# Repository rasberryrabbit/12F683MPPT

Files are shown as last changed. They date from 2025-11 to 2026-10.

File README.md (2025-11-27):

# 12F683MPPT
Simple MPPT with 12F683  
  
Another porting of MPPT. Test ok. Switching frequency : 10kHz.  
It has no switching noise.  
  
BUK9508-55A for alternative FET. 
  
TLC272 OPAMP works better. MCP602 is better for low temperature condition.  
  
(Note) Sometimes MPPT stalls no output. It caused by low FET bootstrap voltage.  
It's very rare condition. It may fixed by R9 change.

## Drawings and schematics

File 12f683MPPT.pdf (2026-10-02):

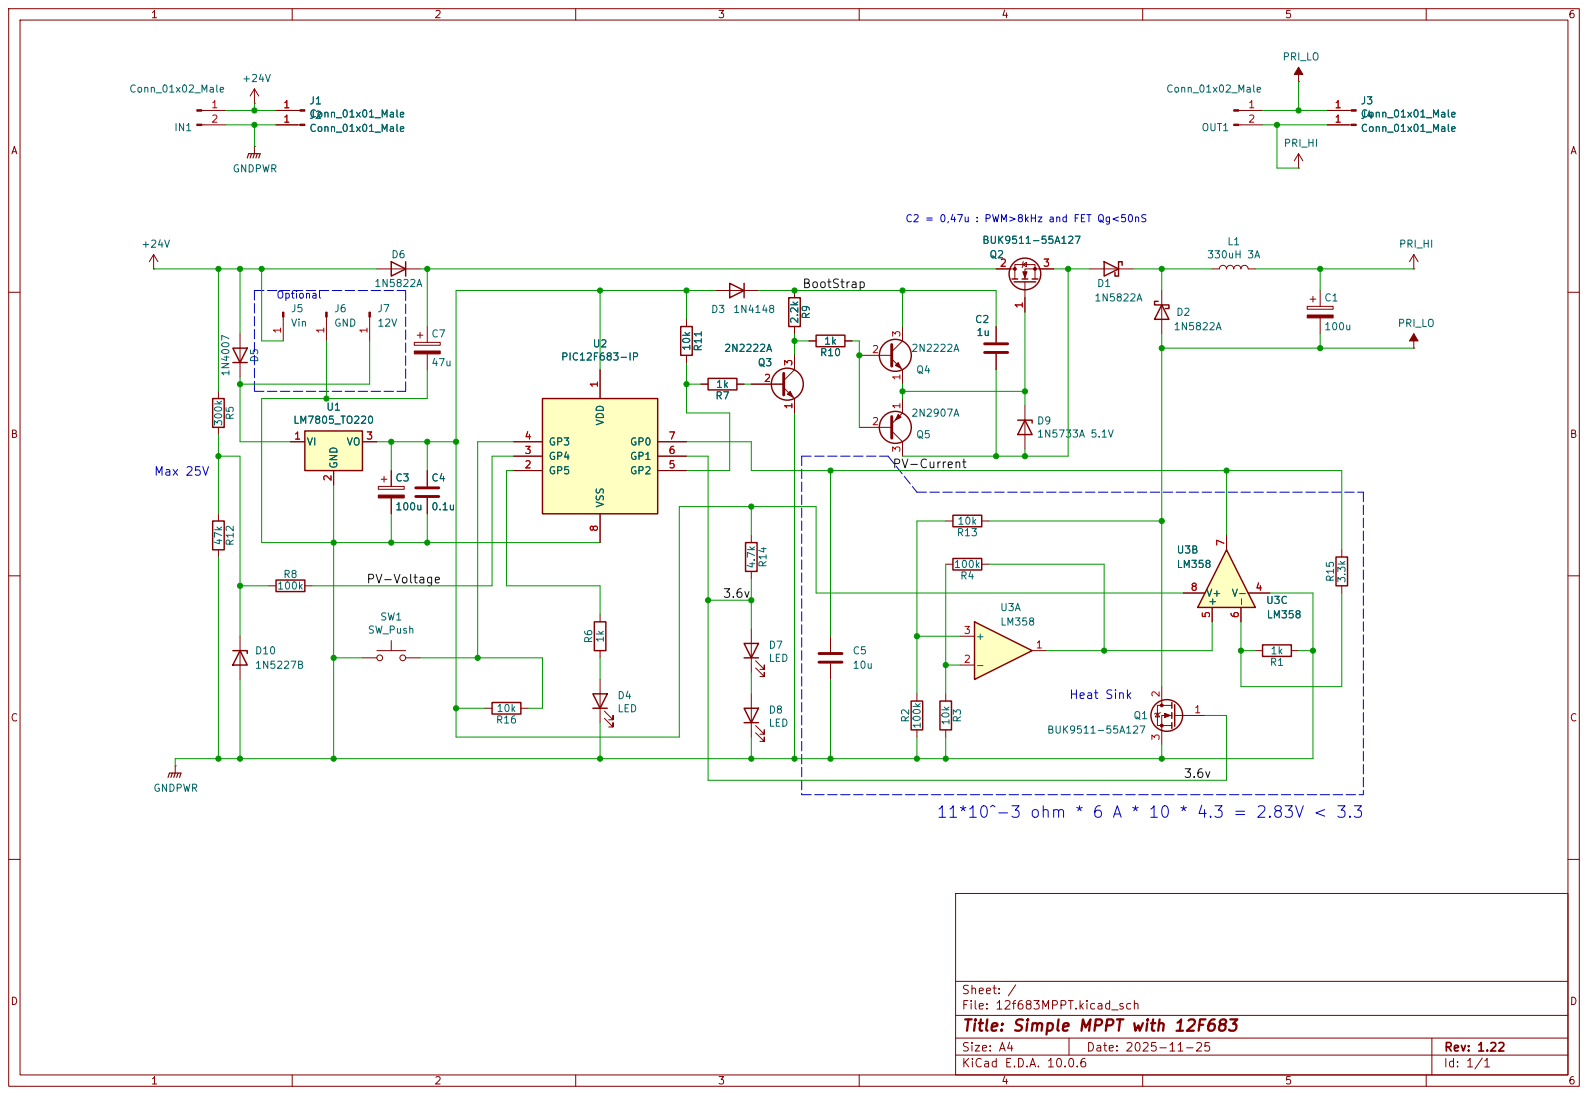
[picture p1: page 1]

C2 = 0,47u : PWM>8kHz and FET Qg<50nS

Sheet: /
File: 12f683MPPT.kicad_sch
Title: Simple MPPT with 12F683

Size: A4 | Rev: 1.22
KiCad E.D.A. 10.0.6 | Id: 1/1

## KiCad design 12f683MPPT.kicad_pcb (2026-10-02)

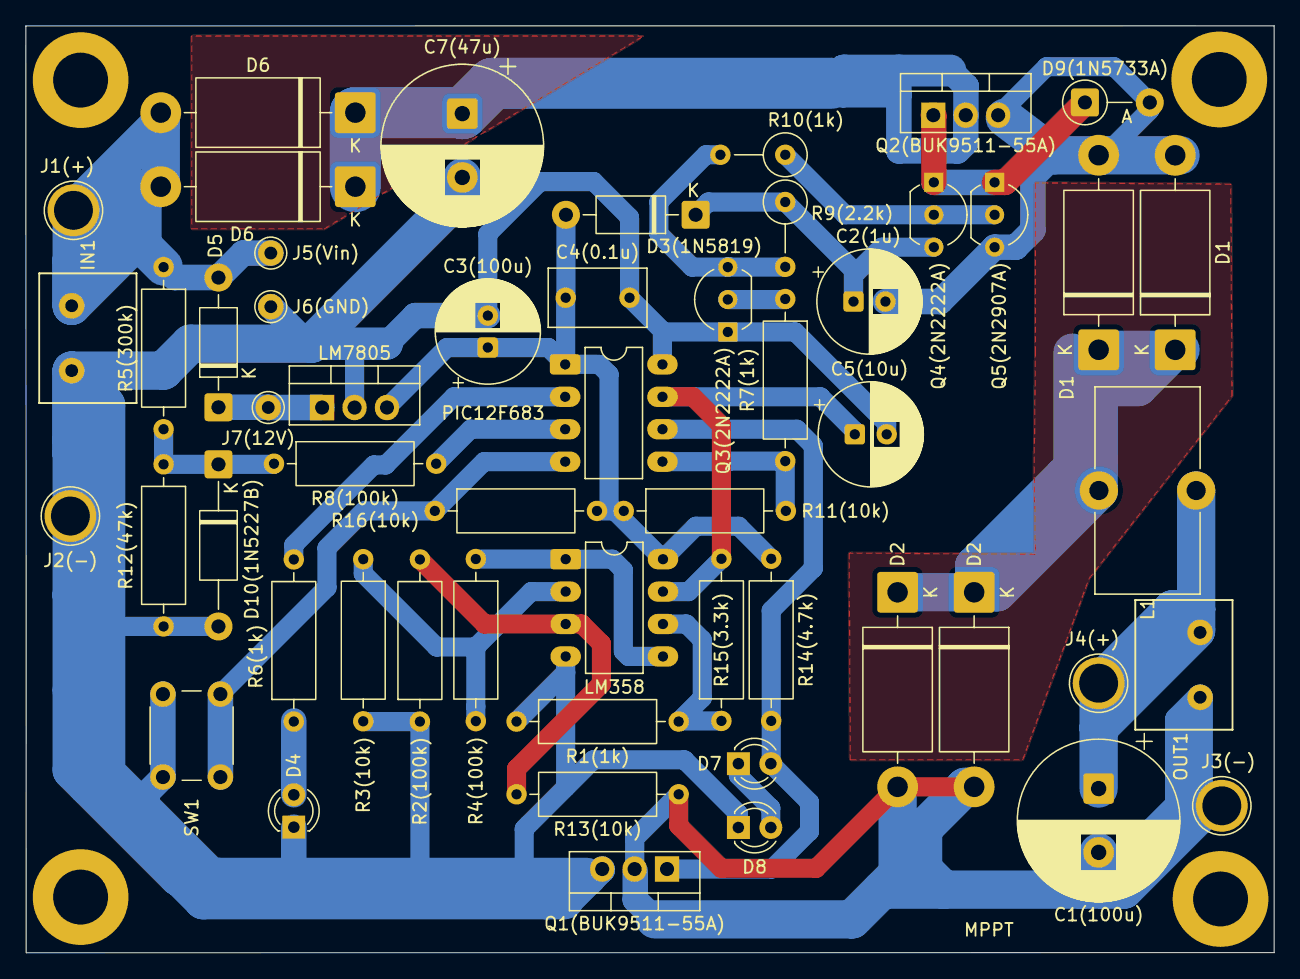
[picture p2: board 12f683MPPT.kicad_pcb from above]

Board: 2 copper layers, 97.8 x 72.6 mm, 54 parts (0 on the bottom side), 27 nets.

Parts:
C1(100u): 100u; CP_Radial_D12.5mm_P5.00mm
C2(1u): 4.7u 50v; CP_Radial_D8.0mm_P2.50mm
C3(100u): 100u; CP_Radial_D8.0mm_P2.50mm
C4(0.1u): 0.1u; C_Disc_D7.5mm_W4.4mm_P5.00mm
C5(10u): 10u; CP_Radial_D8.0mm_P2.50mm
C7(47u): 47u; CP_Radial_D12.5mm_P5.00mm
D1, D1#2, D2, D2#2, D6, D6#2: 1N5822A; D_DO-201AD_P15.24mm_Horizontal
D3(1N5819): 1N5819; D_DO-41_SOD81_P10.16mm_Horizontal
D4, D7, D8: LED; LED_D3.0mm
D5: 1N4007; D_DO-41_SOD81_P10.16mm_Horizontal
D9(1N5733A): 1N5733A 5.1V; D_DO-41_SOD81_P5.08mm_Vertical_AnodeUp
D10(1N5227B): 1N5227B; D_DO-41_SOD81_P12.70mm_Horizontal
IN1: Conn_01x02_Male; Connector_SCREW_2PIN
J1(+), J2(-), J3(-), J4(+): Conn_01x01_Male; 1pin
J5(Vin): Vin; Pin_D1.0mm_L10.0mm
J6(GND): GND; Pin_D1.0mm_L10.0mm
J7(12V): 12V; Pin_D1.0mm_L10.0mm
L1: 330uH 3A; L_Toroid_Vertical_L16.0mm_W8.0mm_P7.62mm
LM358: LM358; DIP-8_W7.62mm_LongPads
LM7805: LM7805_TO220; TO-220-3_Vertical
OUT1: Conn_01x02_Male; Connector_SCREW_2PIN
PIC12F683: PIC12F683-IP; DIP-8_W7.62mm_LongPads
Q1(BUK9511-55A), Q2(BUK9511-55A): BUK9511-55A127; TO-220-3_Vertical
Q3(2N2222A), Q4(2N2222A): 2N2222A; TO-92_Inline_Wide
Q5(2N2907A): 2N2907A; TO-92_Inline_Wide
R1(1k), R6(1k), R7(1k): 1k; R_Axial_DIN0309_L9.0mm_D3.2mm_P12.70mm_Horizontal
R2(100k), R4(100k), R8(100k): 100k; R_Axial_DIN0309_L9.0mm_D3.2mm_P12.70mm_Horizontal
R3(10k), R11(10k), R13(10k), R16(10k): 10k; R_Axial_DIN0309_L9.0mm_D3.2mm_P12.70mm_Horizontal
R5(300k): 300k; R_Axial_DIN0309_L9.0mm_D3.2mm_P12.70mm_Horizontal
R9(2.2k): 2.2k; R_Axial_DIN0309_L9.0mm_D3.2mm_P5.08mm_Vertical
R10(1k): 1k; R_Axial_DIN0309_L9.0mm_D3.2mm_P5.08mm_Vertical
R12(47k): 47k; R_Axial_DIN0309_L9.0mm_D3.2mm_P12.70mm_Horizontal
R14(4.7k): 4.7k; R_Axial_DIN0309_L9.0mm_D3.2mm_P12.70mm_Horizontal
R15(3.3k): 3.3k; R_Axial_DIN0309_L9.0mm_D3.2mm_P12.70mm_Horizontal
SW1: SW_Push; SW_PUSH_6mm_H7.3mm

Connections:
+24V: D5.2 (A), D6.2 (A), D6#2.2 (A), IN1.1, J1(+).1, J5(Vin).1, R5(300k).1
/3.6v: D7.2 (A), PIC12F683.6 (GP1), Q1(BUK9511-55A).1 (G), R14(4.7k).2
/BootStrap: C2(1u).1, D3(1N5819).1 (K), Q4(2N2222A).3 (C), R9(2.2k).1
/PV-Current: C5(10u).1, LM358.7, PIC12F683.7 (GP0), R15(3.3k).2
/PV-Voltage: PIC12F683.3 (GP4), R8(100k).2
GNDPWR: C3(100u).2, C4(0.1u).2, C5(10u).2, C7(47u).2, D4.1 (K), D8.1 (K), D10(1N5227B).2 (A), IN1.2, J2(-).1, J6(GND).1, LM358.4 (V-), LM7805.2 (GND), PIC12F683.8 (VSS), Q1(BUK9511-55A).3 (S), Q3(2N2222A).1 (E), R1(1k).1, R2(100k).1, R3(10k).2, R12(47k).2, SW1.1
unnamed: C2(1u).2, D1.2 (A), D1#2.2 (A), D9(1N5733A).2 (A), Q2(BUK9511-55A).3 (S), Q5(2N2907A).3 (C)
unnamed: D1.1 (K), D1#2.1 (K), D2.1 (K), D2#2.1 (K), L1.1
unnamed: C3(100u).1, C4(0.1u).1, D3(1N5819).2 (A), LM358.8 (V+), LM7805.3 (VO), PIC12F683.1 (VDD), R11(10k).1, R14(4.7k).1, R16(10k).2
unnamed: D4.2 (A), R6(1k).1
unnamed: D5.1 (K), J7(12V).1, LM7805.1 (VI)
unnamed: C7(47u).1, D6.1 (K), D6#2.1 (K), Q2(BUK9511-55A).2 (D)
unnamed: D7.1 (K), D8.2 (A)
unnamed: D9(1N5733A).1 (K), Q2(BUK9511-55A).1 (G), Q4(2N2222A).1 (E), Q5(2N2907A).1 (E)
unnamed: D10(1N5227B).1 (K), R5(300k).2, R8(100k).1, R12(47k).1
unnamed: Q3(2N2222A).2 (B), R7(1k).1
unnamed: Q3(2N2222A).3 (C), R9(2.2k).2, R10(1k).2
unnamed: Q4(2N2222A).2 (B), Q5(2N2907A).2 (B), R10(1k).1
unnamed: PIC12F683.5 (GP2), R7(1k).2, R11(10k).2
unnamed: PIC12F683.4 (GP3), R16(10k).1, SW1.2
unnamed: PIC12F683.2 (GP5), R6(1k).2
unnamed: LM358.3 (+), R2(100k).2, R13(10k).2
unnamed: LM358.2 (-), R3(10k).1, R4(100k).2
unnamed: LM358.1, LM358.5 (+), R4(100k).1
unnamed: LM358.6 (-), R1(1k).2, R15(3.3k).1
PRI_HI: C1(100u).1, J4(+).1, L1.2, OUT1.2
PRI_LO: C1(100u).2, D2.2 (A), D2#2.2 (A), J3(-).1, OUT1.1, Q1(BUK9511-55A).2 (D), R13(10k).1

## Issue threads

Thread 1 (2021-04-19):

Question: Full scale current to ADC?

ElekPat, 2021-04-19:
Hello,

and thank you for sharing your project. I have a question, I do not understand how you can have full scale 3A current match the full scale ADC reading of 1024 (as stated in your code) with the MOSFET Rdson and OPAMP configuration you have in your schematics:

 - 3000 mA x 11 mOhms = 33 mV max
 - U3A Gain = 100K/10K = 10
 - U3B Gain = 1.33
 - Total Gain = 13.3
 - so max voltage on pin GP0 = 33 mV x 13.3 = 439mV
 - but Vref = 3.6V = 3600mV for full scale 1024 reading on ADC

So in fact, you are only using approx 439/3600 = 12% of full scale (max 125 reading on ADC).

Results would be same if 6A max (your total gain is 6.25 in this case with the 47K value you specify).

Thank you,
Patrick

rasberryrabbit, 2021-04-20:
Hello,

It is not designed for accuracy.
The MOSFET resistance value is not fixed that can change with temperature.
Current sensing is not accurate value but it can checking for optimal power.
You can adjust gain values according to your application.

Best regards,
rasberryrabbit

2021년 4월 20일 (화) 오전 12:02, Patrick Tissot ***@***.***>님이 작성:

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

--
Best Regards,

Do-Wan Kim.

ElekPat, 2021-04-20:
Thank you

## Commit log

2019-05-20 First. Not tested yet.
    [12F683MPPT.cfg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]
2019-05-20 update PCB.
    [12f683MPPT-B_Cu.gbr, 12f683MPPT-B_Mask.gbr, 12f683MPPT-B_SilkS.gbr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]
2019-06-03 Fix connector foot print.
2019-06-04 Fix OSC and timer1 prescaler.
2019-06-09 Remove low voltage protection code and test.
2020-05-28 Mount Hole size to 3mm. It's lower value for normal mounting.
    [12f683MPPT-B_Cu.gbr, 12f683MPPT-B_Mask.gbr, 12f683MPPT-B_SilkS.gbr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]
2020-05-28 Fix drl file.
    [12f683MPPT-B_Cu.gbr, 12f683MPPT-B_Mask.gbr, 12f683MPPT-B_SilkS.gbr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]
2020-05-28 Remove invalid drl file.
    [12f683MPPT-NPTH.drl, 12f683MPPT-PTH.drl]
2020-09-30 Change configuration BOREN.
    [12F683MPPT.cfg]
2021-04-28 Enable BOR
    [12F683MPPT.cfg]
2021-04-30 Add zener diode for FET protection.
    [12f683MPPT-B_Cu.gbr, 12f683MPPT-B_Mask.gbr, 12f683MPPT-B_SilkS.gbr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]
2021-05-07 R9 -> 2.2k
    [12f683MPPT-B_Cu.gbr, 12f683MPPT-B_Mask.gbr, 12f683MPPT-B_SilkS.gbr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]
2021-05-28 Mininum PWM limit to 15.
2021-05-30 Set low PWM to 12.
2021-07-09 C2 -> 4.7uF
    [12f683MPPT.sch]
2021-07-29 Try to fix low bootstrap voltage.
    [12f683MPPT.sch]
2021-07-30 Revert PWM_MIN.
2021-07-30 Revert and change Diode.
    [12f683MPPT-B_Cu.gbr, 12f683MPPT-B_Mask.gbr, 12f683MPPT-B_SilkS.gbr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]
2021-08-01 Fix power comparison.
2025-11-25 Fix circuit. R1 -> 1k ohm.
    [12f683MPPT.kicad_pcb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]
2025-11-25 Add new KiCad files.
    [12f683MPPT.kicad_sch]
2025-11-25 Remove old circuit.
    [12f683MPPT.sch]
2025-11-25 Add current measurement hint.
    [12f683MPPT.kicad_sch]
2025-11-26 Fix PWM bug.
2025-11-26 More fix on PWM.
2025-11-27 Set PWM start duty cycle to 30%.
2025-11-27 Try limiting PWM at low current.
2025-11-28 Update PCB options.
    [12f683MPPT.kicad_pcb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]
2025-11-28 Remove old verison files.
    [12f683MPPT-B_SilkS.gbr, 12f683MPPT-F_SilkS.gbr]
2025-12-01 Remove low current counting. It's useless.
2025-12-02 Remove files.
    [12f683MPPT-B_Cu.gbr, 12f683MPPT-B_Mask.gbr, 12f683MPPT-B_Silkscreen.gbr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]
2025-12-02 Update PCB files.
    [12f683MPPT-B_Cu.gbl, 12f683MPPT-B_Mask.gbs, 12f683MPPT-B_Paste.gbp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]
2025-12-02 Update circuit.
    [12f683MPPT.kicad_pcb, 12f683MPPT.kicad_sch]
2025-12-02 Add zener for input voltage limiting.
    [12f683MPPT.kicad_pcb, 12f683MPPT.kicad_sch]
2025-12-02 More PCB files changes.
    [12f683MPPT-B_Cu.gbl, 12f683MPPT-B_Mask.gbs, 12f683MPPT-B_Paste.gbp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]
2025-12-14 Add hint for D3 alternative.
    [12f683MPPT.kicad_sch]
2026-03-11 Increase a little checking interval. Not much changes output power. most stable value is 18ms.
2026-07-21 Change PWM value on start and remove TMR2IF bit checking.
2026-07-22 Try to fix when decreasing current.
2026-07-31 Remove voltage multiplication operation.
2026-07-31 Change the current measurement method.
2026-07-31 Improved PWM settings changes. No change in functionality.
2026-08-01 Changed sampling method for more power output
2026-08-12 Restore voltage multiplier.
2026-08-13 Loosen power low checking.
2026-08-13 Use adc average values.
2026-08-21 Add option for ADC sampling. No functional changes.
2026-09-05 Set low PWM to 10%.
2026-09-05 Remove C5 capacitor.
    [12f683MPPT.kicad_sch]
2026-09-05 Revert "Remove C5 capacitor."
    This reverts commit 91564baa6f44f8037db3e26806d1f3bf7336a2bb.
    [12f683MPPT.kicad_sch]
2026-09-05 Using ceramic capacitor.
    [12f683MPPT.kicad_sch]
2026-09-07 Avoid falling ringing at current measuring.
2026-09-08 Add switch reset.
2026-09-08 Change bootstrap diode D3 to 1N4148.
    [12f683MPPT.kicad_sch]
2026-09-22 Use dead band for more power output.
2026-09-23 Disable low current checking.
2026-09-24 Solved the problem of PWM being fixed.
2026-09-25 To more reliably compare cumulative power changes, we adjust the update time and limit the maximum deadband at high powers to less than 1%.
2026-09-25 Reduce low current limit.
2026-09-25 Update PWM @ no load.
2026-09-25 Change C2 to 1uF ceramic.
    [12f683MPPT.kicad_sch]
2026-09-26 Update foot print.
    [12f683MPPT.kicad_sch]
2026-10-02 Hints on the capacity of the bootstrap capacitor C2.
    [12f683MPPT.kicad_pcb, 12f683MPPT.kicad_sch]
2026-10-07 Deadband switching function 0.538% and 0.561%. Improved to enable toggle selection with power on.
2026-10-07 Ignores previously stored ADC values and uses only the upper 3 bits.
